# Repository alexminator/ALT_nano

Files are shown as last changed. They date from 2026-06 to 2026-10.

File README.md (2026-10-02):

<h1 align="center">
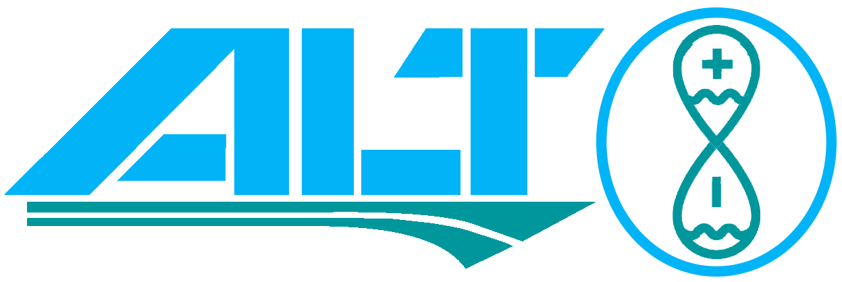
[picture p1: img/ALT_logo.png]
ALT logo
  <br/><strong>Another Level Tank</strong>
  
  <a href="https://github.com/alexminator/ALT_nano/blob/master/README_es.md">
    
  </a>
  <a href="https://github.com/alexminator/ALT_nano/blob/master/README.md">
    
  </a>
</h1>

<h1 align="center">
  


 



  
</h1> 

<h4 align="center">:star: Give me one star — it will motivate me to keep improving it!!</h4>

<!-- TABLE OF CONTENTS -->
<details>
  <summary>Table of contents</summary>
  <ol>
    <li>
      <a href="#about-the-project">About the Project</a>
      <ul>
        <li><a href="#goals-of-this-project-">Goals of this project</a></li>
      </ul>
    </li>
    <li>
      <a href="#getting-started">Getting Started</a>
      <ul>
        <li><a href="#component">Component</a></li>
        <li><a href="#installation">Installation</a></li>
        <li><a href="#diagram">Diagram</a></li>
        <li><a href="#build-and-upload">Build and upload</a></li>
      </ul>
    </li>
    <li><a href="#calibration-and-configuration">Calibration and configuration</a></li>
    <li><a href="#operation">Operation</a></li>
    <li><a href="#troubleshooting">Troubleshooting</a></li>
    <li><a href="#to-do">To do</a></li>
    <li><a href="#collaborator">Collaborator</a></li>
    <li><a href="#license">License</a></li>
    <li><a href="#contact">Contact</a></li>
    <li><a href="#open-source-programs">Open Source Programs</a></li>
    <li><a href="#special-thanks">Special thanks</a></li>
  </ol>
</details>

<!-- ABOUT THE PROJECT -->
## About the Project

ALT_nano is an Arduino-based tank monitor. An ultrasonic sensor measures the distance from the sensor to the water surface, and a 20×4 LCD shows the estimated level and volume. A buzzer signals configurable low- and high-level alarms; the button silences an active alarm or wakes the display backlight. This project is a monitoring aid and is not a certified overflow-protection system.

**You can view the demo [here](https://wokwi.com/projects/356392498196222977).**
> **Warning** :
In Wokwi, press **Start** and click the ultrasonic sensor to change its simulated distance. The firmware currently accepts readings from **20 to 104 cm** (`DEAD_ZONE` and `DIST_TOPE`). At 104 cm the tank is treated as empty; a 20 cm reading maps to 100% on the configured scale. For that reading to represent a physically full tank, the sensor offset above the tank rim (`S`) must also be 20 cm, matching `DEAD_ZONE`. The JSN-SR04T documentation specifies a nominal 25 cm blind zone; for a 25 cm mounting offset, set both `S` and `DEAD_ZONE` to 25 cm after confirming reliable readings with your sensor. The displayed 100% is a software scale, not a guarantee that the tank cannot overflow.

### Goals of this project :

- **_24/7 tank level monitoring_**
- **_Avoid spillage of water due to overflow_**
- **_Prevent the tank from being empty and leaving the house without a water supply_**



---

<!-- GETTING STARTED -->
## Getting Started



```js
         .8.          8 8888         8888888 8888888888
        .888.         8 8888               8 8888
       :88888.        8 8888               8 8888
      . `88888.       8 8888               8 8888
     .8. `88888.      8 8888               8 8888
    .8`8. `88888.     8 8888               8 8888
   .8' `8. `88888.    8 8888               8 8888
  .8'   `8. `88888.   8 8888               8 8888
 .888888888. `88888.  8 8888               8 8888
.8'       `8. `88888. 8 888888888888       8 8888

```
### Component

This project uses an Arduino Nano, a 20×4 parallel LCD, an ultrasonic distance sensor, a buzzer, and a push button. The example hardware uses a waterproof **JSN-SR04T** sensor. If you use another sensor, confirm its voltage, range, timing, and minimum reliable distance before connecting it.

The Arduino(Hardware) components required are:

- **Arduino Nano**
- **LCD screen 20x4**
- **A button**
- **A buzzer**
- **A 10 kΩ resistor** (button pull-up)
- **A 10 kΩ potentiometer** (LCD contrast)
- **A waterproof ultrasonic sensor [JSN-SR04T](https://naylampmechatronics.com/img/cms/Datasheets/JSN-SR04T-2-0.pdf)**



---

### Installation

*Below is the connection diagram and a table with the pins to be connected.*

| ARDUINO PINS | LCD PINS |  
| --- | --- |
|  12-  `D12`  | 15 - `A`  |
|  11-  `D11`  | 4 - `RS`  |
|  10-  `D10`  | 6 - `E` |
|  9-  `D9` | 11 - `D4` |
|  8-  `D8` | 12 - `D5` |
|  7-  `D7` | 13 - `D6` |
|  6-  `D6` | 14 - `D7` |
| GND | 16 - `K`  |
| GND | 1 - `VSS` |
| VCC(5v) | 2 - `VDD` |
| ARDUINO PINS | BUTTON PINS | 
|  3-  `D3` | 1 - 3 | 
| GND | 2 - 4 |  
| ARDUINO PINS | BUZZER PINS |
|  4-  `D4` | + |
| GND | - |
| ARDUINO PINS | JSN-SR04T |
|  2-  `D2` |  `TRIGGER`  |
|  5-  `D5` | `ECHO` |
| VCC(5v) | VCC |
| GND | GND |

**LCD setup:** Connect `R/W` (LCD pin 5) to GND. Connect `V0` (pin 3, contrast) to the wiper of a 10 kΩ potentiometer, with its ends connected to 5 V and GND. Adjust the potentiometer until the characters are visible.

> **Button wiring:** This firmware configures D3 as `INPUT` (not `INPUT_PULLUP`). Wire the button and external 10 kΩ pull-up resistor according to the circuit diagram, and verify that the input reads HIGH when idle and LOW when pressed. Do not connect the LCD backlight pin directly if the module's current exceeds the Arduino pin rating; use an appropriate transistor/driver if needed.

### Diagram

Diagram

> ### :point_right: You can find the diagram [here](https://github.com/alexminator/ALT_nano/blob/master/img/ALT-UNO.fzz). :star:


---

## Build and upload

This is a PlatformIO project for an **Arduino Nano ATmega328P**. Install [VS Code](https://code.visualstudio.com/) and the [PlatformIO IDE extension](https://platformio.org/install/ide?install=vscode), open this repository as a project, and allow PlatformIO to install the dependencies listed in `platformio.ini`. Select the Nano ATmega328P board profile (and the correct bootloader/processor variant if your board requires it).

From the PlatformIO terminal, build and upload with:

```sh
pio run
pio run --target upload
```

Select the correct serial port in PlatformIO if it is not detected automatically. To use the command line, install PlatformIO Core and run the same commands from the project directory.

## Code and debugging

The `Tank` library draws the tank animation; `LiquidCrystal` drives a parallel 20×4 LCD; `NewPing` reads the ultrasonic sensor. The other source files handle alarms, sound, custom LCD characters, and diagnostics. The current firmware uses a **parallel LCD**, not an I2C backpack. Switching to I2C requires changing the library, pin wiring, and initialization.

To enable diagnostic serial output, change the definition near the top of `src/main.cpp`:

```cpp
#define DEBUGLEVEL DEBUGLEVEL_DEBUGGING
// #define DEBUGLEVEL DEBUGLEVEL_NONE
```

The serial monitor is configured for **9600 baud**. Available verbosity levels are defined in `src/debug.h`.

The ultrasonic sensor measures **D**, the distance from its face to the water surface. **H** is the tank's internal height (top rim to bottom), **S** is the vertical sensor offset above the rim, and **C** is the water-column height (bottom to water surface). The general formula is **C = H + S − D**. With an empty tank, the sensor measures to the bottom, so **`DIST_TOPE = D = H + S`**.

The diagram compares four cases:

1. **Empty tank, sensor flush:** `S = 0`, `C = 0`, and `DIST_TOPE = D = H`.
2. **Empty tank, sensor 25 cm above the rim:** `S = 25 cm`, `C = 0`, and `DIST_TOPE = D = H + S`.
3. **Water at an intermediate level, sensor flush:** `S = 0`, so `C = H − D`.
4. **Water at an intermediate level, sensor 25 cm above the rim:** `S = 25 cm`, so `C = H + S − D`. The 25 cm offset is the nominal JSN-SR04T blind-zone clearance; verify the actual minimum for your sensor.

For the nominal 25 cm setup, configure `DEAD_ZONE = 25 cm` and `DIST_TOPE = H + 25 cm`.

<figure>
  Four tank diagrams showing measurements H, S, D, C and the DIST_TOPE formulas
  <figcaption>Sensor-to-water distance and tank geometry used by the level calculation.</figcaption>
</figure>

### What 100% means for a 110 cm tank

With `H = 110 cm` and `DEAD_ZONE = 25 cm`, the software's maximum liquid-column scale is `DIST_TOPE − DEAD_ZONE`:

- **Sensor flush with the rim (`S = 0`):** `DIST_TOPE = 110 cm`; at the displayed 100%, `C = H − D = 110 − 25 = 85 cm`. The water is still 25 cm below the rim because the blind-zone distance is subtracted from the tank height.
- **Sensor 25 cm above the rim (`S = 25 cm`):** `DIST_TOPE = H + S = 135 cm`; at 100%, `C = 135 − 25 = 110 cm`. When full, `D = 25 cm` and `C = H = 110 cm`, so 100% coincides with the tank rim.

These are example settings, not the current firmware values (`DIST_TOPE = 104 cm`, `DEAD_ZONE = 20 cm`). Configure and verify the values for the actual tank and sensor before using either scale.

<figure>
  Comparison of the 100 percent level in a 110 cm tank with a flush sensor and a sensor 25 cm above the rim
  <figcaption>Example of the configured 100% point for two sensor mounting heights.</figcaption>
</figure>

### Calibration and configuration

The main settings are in `src/main.cpp`:

| Setting | Current value | Meaning |
| --- | ---: | --- |
| `DIST_TOPE` | 104 cm | Sensor-to-bottom reading when the tank is empty. With **H** as tank height and **S** as sensor offset above the rim, use `DIST_TOPE = H + S` (or directly measure this distance with the tank empty). |
| `DEAD_ZONE` | 20 cm | Minimum accepted sensor distance and distance mapped to 100% by the current software scale. The JSN-SR04T specifies a nominal 25 cm blind zone; the current 20 cm setting is empirical. To map 100% to water at the rim while retaining 25 cm clearance, configure both `DEAD_ZONE = 25 cm` and `S = 25 cm`, then recalculate `DIST_TOPE = H + S`. For example, if **H = 104 cm**, use `DIST_TOPE = 129 cm`. Verify your particular sensor's reliable minimum. |
| `MAX_DISTANCE` | 200 cm | Maximum distance requested from NewPing; must cover the installed tank while remaining within the sensor's range. |
| `NIVEL_BAJO` / `NIVEL_ALTO` | 20% / 100% | Low- and high-level alarm thresholds. |
| `ancho`, `largo`, `tabiqueA`, `tabiqueL` | cm | Rectangular tank and central-partition dimensions used by the volume formula. |

Measure and verify these values with the actual tank and sensor. The current firmware uses `DIST_TOPE = 104 cm` and `DEAD_ZONE = 20 cm`; `DIST_TOPE` is the sensor-to-bottom reading when empty (**H + S**), not necessarily the tank's height. The accepted distance interval is currently **20–104 cm**. Readings closer than the configured minimum or farther than `DIST_TOPE` are treated as invalid. The level is clamped to 0–100%; with `S = DEAD_ZONE`, 100% corresponds to the water reaching the tank rim. If these values differ, 100% is only the configured software scale and will not coincide with a physically full tank. In either case, **100% does not guarantee overflow is impossible**: set the high alarm below the actual overflow point and leave a safe margin.

The current volume formula assumes a rectangular tank with one rectangular central partition that displaces water. For another shape or partition, adapt `Sensor::get_volume()`; the LCD volume will otherwise be inaccurate. The sensor-to-water geometry also assumes the water surface is a suitable ultrasonic target; avoid obstructions, narrow openings, turbulence, and angled surfaces where possible. Validate the displayed volume against a known water quantity before relying on it.

### Operation

- The LCD shows level (%), sensor distance (cm), estimated volume (L), and a tank-fill graphic.
- A low- or high-level alarm is confirmed after **10 consecutive valid readings** at the threshold. Invalid sensor readings are filtered; after **3 consecutive invalid readings**, the display reports a sensor error.
- Hold the button to silence an active alarm. The alarm can sound again after its condition clears and reoccurs.
- A button press wakes the LCD backlight. The backlight automatically turns off after about **60 seconds**; an active alarm wakes it.

### Troubleshooting

| Symptom | Checks |
| --- | --- |
| `ERROR` on the LCD | Check sensor power, common GND, TRIG on D2, ECHO on D5, sensor aim, and whether the measured gap is within `DEAD_ZONE`–`DIST_TOPE`. |
| Level or volume looks wrong | Re-measure `DIST_TOPE` and tank dimensions; confirm cm units and that the tank shape matches the formula in `get_volume()`. |
| Readings jump near the water | Keep the sensor perpendicular to a calm water surface; verify the minimum reliable distance and increase `DEAD_ZONE` if necessary. |
| Alarm does not match the desired level | Adjust `NIVEL_BAJO` / `NIVEL_ALTO`; remember that the alarm also requires 10 consecutive readings. |
| LCD is blank or unreadable | Check LCD power/contrast, the parallel wiring table, and the backlight circuit; verify the Nano board/port before uploading. |

This project is a monitoring aid, not a certified safety or overflow-prevention device. Use an independent float switch or other fail-safe where overflow could cause damage. The ultrasonic sensor, wiring, and electronics must be installed in a suitably protected environment.



---

## To do

The following items are ideas for future development; they are **not implemented in the current firmware**.

*Make a universal version of the project that includes the following features.*

**_For the software part:_**

+ Include a menu to configure **ALL** possible variables.
  - Tank type. For an accurate calculation of the volume of water.
      * Cylindrical or rectangular.
  - Tank dimensions. The height of the tank can be entered both manually and automatically.
  - Level to activate the alarm for low and high.
  - Choice of the working mode of the device. 
      * Manual the user makes the decisions. 
      * Automatic when reaching the low level of the tank, the level in the cistern will be measured, if it is sufficient, the pump will be activated and the tank will be filled.
  - Choice of alarm tone.
  - Include the incoming water flow to be displayed on the screen.
  - Choice of information to display on the screen.

**_For the hardware part:_**

+ Being able to use different screens. 
     - LCD.
     - OLED
+ Increase the number of buttons to 3, for easy menu navigation.
+ Add relay module to control the tank filling pump.
+ Add a flow sensor to protect the filling pump and account for the amounts of water entering the tank.
+ Add a second ultrasonic sensor to measure the level of the reservoir and that the filling is automatic when the low level is reached.
+ And finally, if time is enough for me, I can make a version with esp32 that includes an embedded website and do all the control from your mobile.



---

## Collaborator

<table style="width:100%">
  <tr>
    <th><b>Alexminator</b></th>
    <th><b>20-EverGreen-2</b></th>
    
  </tr>
  <tr>
    <td align="center"><a href="https://github.com/alexminator">alexminator</a></td>
    <td align="center"><a href="https://github.com/20-EverGreen-2">20-EverGreen-2</a></td>
    
  </tr>
  <tr>
    <td align="center">  </td>
    <td align="center"></td>
    
  </tr>
</table>

## License

*The ALT project is released under the [MIT](LICENSE) license.*

## Contact

> **_Need help?_** 
**_Feel free to contact me 📨 [alexminator99@gmail.com](mailto:alexminator99@gmail.com?Subject=ALT_nano_issues)_**

 

## Open Source Programs
* [VSCODE](https://code.visualstudio.com/) -A source code editor.
* [PlatFormio](https://platformio.org/) - Open programming IDE for C/C++, hardware oriented.

## Special thanks
* _To the Cuban Arduino community._
* _To everyone who gave me his help when I had doubts, especially my son._



---

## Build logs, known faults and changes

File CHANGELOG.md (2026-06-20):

# Changelog - ALT_nano

## [2026-06-20] - Revisión y Corrección de Bugs

### 🐛 Bugs Críticos Corregidos

#### 1. División por cero en `buzz()` (`src/buzzer.h`)
- **Problema:** `buzzer_intro()` llamaba a `buzz(BUZZER_PIN, 0, noteDuration)` para silencios entre notas. Con `frequency=0`, el cálculo `1000000 / frequency / 2` causaba una división por cero, colgando el Arduino.
- **Solución:** Agregado guard `if (frequency <= 0) return;` al inicio de `buzz()`.

#### 2. Índice CGRAM fuera de rango en `createChars()` (`src/font.h`)
- **Problema:** El LCD HD44780 solo tiene 8 slots CGRAM (0-7), pero `createChars()` registraba el carácter `LT` en el slot 8 (inválido). Además `lcd.write(8)` en `printBigCharacters()` no renderizaba un custom character sino un caracter de ROM.
- **Solución:** `LT` movido a slot 0, todos los `lcd.write(8)` → `lcd.write(0)`.

### 🟠 Bugs Graves Corregidos

#### 3. Alarmas bloqueantes (`src/alarms.h`)
- **Problema:** `alarmlow()` y `alarmfull()` usaban bucles `while` que bloqueaban todo el sistema: no se leía el sensor, no se actualizaba la pantalla, y el botón era la única salida. Si el botón fallaba, el sistema quedaba atrapado para siempre.
- **Solución:** Reescritura completa del sistema de alarmas usando `millis()` no bloqueante. El buzzer suena cada 2 segundos en vez de constantemente. El botón se lee en cada ciclo del `loop()` principal. Los contadores se resetean correctamente al descartar la alarma.

#### 4. Doble lectura del sensor por ciclo (`src/main.cpp`)
- **Problema:** `get_dist()` se llamaba dos veces por cada `loop()` — una dentro de `get_level()` y otra directamente. Cada llamada ejecuta `ping_median()` (5 lecturas ultrasónicas), duplicando el tiempo del loop (~300ms total) y el consumo de energía.
- **Solución:** `distance` se cachea dentro de `get_level()` (`distance = currentDistance`) y se eliminó la llamada redundante en `loop()`.

#### 5. Variables zombie `lowlvl`/`lvlfull` (`src/main.cpp`)
- **Problema:** Estas variables globales solo eran usadas por las antiguas funciones de alarma bloqueantes. Quedaron huérfanas tras la refactorización.
- **Solución:** Eliminadas.

#### 6. Contadores de alarma sin reset (`src/alarms.h`)
- **Problema:** `low_read` y `full_read` nunca se reseteaban después de una alarma, causando que siguieran incrementándose sin límite (eventual overflow de `int`). La alarma se re-ejecutaba inútilmente cada ciclo sin sonar.
- **Solución:** Reseteo de contadores al descartar la alarma (líneas 28, 53) y al volver a nivel normal (líneas 61-62).

#### 7. Include guard en `Tank.cpp` (`lib/Tank/Tank.cpp`)
- **Problema:** Todo el archivo de implementación estaba envuelto en `#ifndef Tank_h` / `#define Tank_h` / `#endif`, que es un patrón de headers, no de archivos .cpp. Podía causar problemas de linking en ciertos entornos.
- **Solución:** Eliminado el include guard. El archivo ahora solo contiene los `#include` necesarios y la implementación.

#### 8. Array mal indexado en glyph `BC20` (`lib/Tank/Tank.cpp:160`)
- **Problema:** En el caso `BC20` del switch, la última línea del array escribía en `array[0]` en vez de `array[7]`, sobrescribiendo el primer byte y causando un glitch visual en la representación del 20% del tanque.
- **Solución:** Cambiado `array[0] = 0x00;` → `array[7] = 0x00;`.

#### 9. Backlight sin reset al activarse por alarma (`src/alarms.h`)
- **Problema:** Cuando una alarma encendía el backlight (que estaba dormido), no se reseteaba `startMillis`. En el siguiente ciclo del `loop()`, la comprobación de sleep veía que había pasado más de `sleep_time` desde el último apagado, y volvía a apagar el backlight inmediatamente.
- **Solución:** `startMillis = now` al encender el backlight desde las alarmas.

### 🚀 Mejoras Implementadas

#### 10. Watchdog Timer (`src/main.cpp`, `src/buzzer.h`)
- Agregado `#include <avr/wdt.h>` y `wdt_enable(WDTO_4S)` en `setup()`.
- `wdt_reset()` al inicio de cada `loop()`.
- `wdt_reset()` adicional dentro de los loops de `buzzer_finish()` para prevenir reset durante la reproducción de tonos largos (~360ms).
- **Beneficio:** Si el software se cuelga (bucle infinito, división por cero no atrapada, etc.), el watchdog reinicia el Arduino automáticamente después de 4 segundos.

#### 11. Wake de backlight por botón (`src/main.cpp`)
- Al presionar cualquier botón (press o hold), el backlight se enciende y el timer de sleep se resetea.
- **Beneficio:** El usuario puede "despertar" la pantalla sin esperar a una alarma.

#### 12. Histéresis en detección de fallo del sensor (`src/main.cpp`)
- Variables agregadas: `sensorFailCount`, `SENSOR_FAIL_THRESHOLD = 3`.
- Se requieren 3 lecturas malas consecutivas para declarar `sensorFail = true`.
- Se requieren 3 lecturas buenas consecutivas (decremento por cada una) para limpiar `sensorFail`.
- **Beneficio:** Elimina falsos positivos por lecturas erráticas esporádicas del sensor ultrasónico.

#### 13. Macros de notas musicales sin fugas (`src/buzzer.h`)
- `#define NOTE_C7` etc. movidas fuera de `buzzer_intro()` y convertidas a `static const int`.
- **Beneficio:** Las constantes ya no contaminan el namespace global. Type-safe.

#### 14. Arrays de melodía en flash en vez de stack (`src/buzzer.h`)
- Arrays `melody[]` y `tempo[]` cambiados a `static const`.
- **Beneficio:** Ya no se copian al stack cada vez que se llama a `buzzer_intro()`. Ahorran RAM (~60 bytes) en un microcontrolador con solo 2KB.

#### 15. Dependencia muerta eliminada (`platformio.ini`)
- `bblanchon/ArduinoTrace@^1.2.0` eliminado de `lib_deps` porque nunca se usa en el código.
- **Beneficio:** Libera ~2KB de flash de programa.

#### 16. Link-Time Optimization activado (`platformio.ini`)
- Agregado `build_flags = -flto`.
- **Beneficio:** Reduce el tamaño del binario final eliminando código muerto entre unidades de compilación.

#### 17. Borrado preciso de campos LCD (`src/main.cpp`)
- Los espacios "mágicos" de ancho fijo (8, 10, 16 espacios) se reemplazaron por padding del tamaño exacto del campo (3 chars para nivel/distancia, 7 para volumen).
- `litros` ahora se imprime con 1 decimal (`litros, 1`) para controlar el ancho.
- **Beneficio:** Elimina caracteres fantasma en la LCD al cambiar entre valores de diferente longitud.

#### 18. Ternarias redundantes eliminadas (`src/main.cpp`)
- `isValidReading()` y `isRandomReading()` ya no usan `? true : false` innecesario.
- **Beneficio:** Código más limpio, sin cambio de comportamiento.

#### 19. `buzzer_notify()` refactorizado (`src/buzzer.h`)
- Los números mágicos repetitivos (`56.818125`) se reemplazaron por constantes con nombre.
- El patrón repetido de 5 notas se reemplazó por un array + bucle `for`.
- **Beneficio:** Código mucho más mantenible y legible.

#### 20. Variables muertas eliminadas (`src/main.cpp`)
- `duration` (nunca leída), `char_y` (nunca usada) eliminadas.
- **Beneficio:** menos basura global, ~4 bytes de RAM liberados.

#### 21. `sizeof` idiomático (`src/buzzer.h`)
- `sizeof(melody) / sizeof(int)` → `sizeof(melody) / sizeof(melody[0])`.

#### 22. Conflicto NewPing/Tone por TIMER2 resuelto (`.pio/libdeps/.../NewPing.h`)
- **Problema:** NewPing y la librería `tone()` de Arduino intentan usar TIMER2 simultáneamente, causando `multiple definition of __vector_7` en el linkeo.
- **Solución:** Agregado `__AVR_ATmega328P__` a la lista de microcontroladores que deshabilitan el timer de NewPing. Esto no afecta a `ping_median()` (que usa `delayMicroseconds()`).

#### 23. Boot loop por watchdog en `setup()` (`src/main.cpp`, `src/buzzer.h`)
- **Problema:** `wdt_enable(WDTO_4S)` al inicio de `setup()` iniciaba la cuenta regresiva, pero `setup()` tarda ~5s en total (logo + `buzzer_intro` de ~3s + `delay`s). El watchdog reseteaba el chip antes de alcanzar `loop()`, causando un ciclo infinito de reinicios.
- **Solución:** Agregados `wdt_reset()` estratégicos: antes y después de `buzzer_intro()` en `setup()`, y dentro del bucle de notas de `buzzer_intro()` para que cada nota (~190ms) refresque el watchdog.

### 📊 Resumen de Archivos Modificados

| Archivo | Cambios |
|---|---|
| `src/main.cpp` | WDT, cacheo de sensor, histéresis, wake por botón, limpieza de variables, padding LCD |
| `src/alarms.h` | Reescritura completa no bloqueante, reset de contadores y backlight |
| `src/buzzer.h` | Guard división por cero, const int, arrays static, wdt_reset, refactor notify |
| `src/font.h` | CGRAM slot 0 para LT, write(0) en vez de write(8) |
| `lib/Tank/Tank.cpp` | array[7] corregido, include guard movido a Tank.h |
| `lib/Tank/Tank.h` | Include guard agregado |
| `platformio.ini` | ArduinoTrace eliminado, -flto agregado, monitor_speed |

### 🧹 Limpieza de Conflictos Merge

#### 24. Eliminación de marcadores de conflicto git y código duplicado
- **Problema:** Todos los archivos modificados (`main.cpp`, `buzzer.h`, `alarms.h`, `font.h`) tenían marcadores `<<<<<<<`, `=======`, `>>>>>>>` de un merge conflict mal resuelto. Ambos lados del conflicto se conservaron, resultando en funciones duplicadas, lógica corrupta y código que no compilaba.
- **Solución en `main.cpp`:** Eliminados duplicados de `isValidReading()`, `isRandomReading()`, `get_level()` (lógica de sensor duplicada con ambos lados del merge), `show_info()` (tres campos impresos dos veces), y `loop()` (lectura doble del sensor).
- **Solución en `buzzer.h`:** Reescrito completamente para eliminar versiones duplicadas de `buzzer_intro()`, `buzzer_notify()` y `buzzer_finish()`.
- **Solución en `alarms.h`:** Eliminada versión antigua bloqueante embebida dentro de la nueva función `alarmcheck()`.
- **Solución en `font.h`:** Eliminados `lcd.createChar(8, LT)` duplicado y bloques de renderizado duplicados para caracteres 'O' y 'A'.

## [2026-06-20] - Segunda Revisión: Include Guard, Ghost A, Mejoras

### 🔴 Crítico

#### 25. Include guard en el archivo equivocado (`lib/Tank/Tank.h`, `lib/Tank/Tank.cpp`)
- **Problema:** `Tank.cpp` tenía `#ifndef Tank_h`/`#define Tank_h`/`#endif` envolviendo toda la implementación (válido para headers, no para .cpp). `Tank.h` no tenía include guard — si se incluía dos veces desde distintos módulos, fallaba en compilación.
- **Solución:** Movido el include guard a `Tank.h` (antes de `#include <LiquidCrystal.h>`), eliminado de `Tank.cpp`.

### 🟠 Graves

#### 26. Carácter fantasma "A" al descartar alarma (`src/main.cpp`)
- **Problema:** La alarma imprime `"ALARMA NIVEL BAJO"` empezando en columna 1, fila 0. `show_info()` limpiaba desde columna 2 con 16 espacios, dejando visible la "A" de "ALARMA" en columna 1.
- **Solución:** `lcd.setCursor(2, 0)` → `lcd.setCursor(0, 0)` con 20 espacios para limpiar toda la fila 0.

### 🟡 Medios

#### 27. Asignación redundante en BC20 (`lib/Tank/Tank.cpp`)
- `array[0] = 0x00;` duplicado tras `array[7] = 0x00;` (merge leftover). Eliminado.

#### 28. Variable `char_y` declarada pero nunca usada (`src/main.cpp`)
- Eliminada. Ahorro: 1 byte de RAM.

#### 29. Draw struct con miembro `level` muerto (`src/main.cpp`)
- `levels()` usaba la global `nivel`, ignorando `this->level`. Eliminado el campo y la inicialización.

### 🚀 Mejoras

#### 30. DEBUGLEVEL cambiado a NONE para producción (`src/main.cpp`)
- `DEBUGLEVEL_DEBUGGING` → `DEBUGLEVEL_NONE`. Ahorro: ~3600 bytes de flash (todo el código de Serial.print compilado condicionalmente).

#### 31. `randomReadingsThreshold` hecho `const` (`src/main.cpp`)
- Era `int randomReadingsThreshold = 2;` — ahora `const int`. El compilador puede optimizar mejor.

#### 32. Debounce competitivo eliminado en `get_level()` (`src/main.cpp`)
- Había dos mecanismos de recuperación de `sensorFail` compitiendo: uno gradual (decremento de `sensorFailCount` en cada lectura buena) y uno instantáneo (`sensorFail = false` incondicional). Eliminado el instantáneo; el gradual es más robusto.

#### 33. `ledbacklight` sincronizado en alarmas (`src/alarms.h`)
- Cuando una alarma encendía el backlight físico (`digitalWrite(LEDBACK, HIGH)`), la variable `ledbacklight` quedaba en `false`. Agregado `ledbacklight = true` en ambos bloques de alarma (baja y alta).

### 🐛 Corrección de Regresión en Alarma

#### 34. Texto de alarma parpadeante (`src/main.cpp`)
- **Problema:** `show_info()` borraba la línea 0 completa en cada ciclo del `loop()`, y `alarmcheck()` escribía el texto de alarma justo antes. El resultado era que el texto se borraba y reescribía cada ~200ms, causando un parpadeo visible.
- **Solución:** El borrado de la línea 0 ahora es condicional: solo se limpia cuando NO hay alarma activa (`low_read < sameReadings && full_read < sameReadings`).

#### 35. Alarma con sonido continuo no bloqueante (`src/buzzer.h`, `src/alarms.h`)
- **Problema:** `buzzer_finish()` usaba `delay(3.6ms)` dentro de un bucle, bloqueando el sistema ~360ms. Se llamaba cada 2 segundos (intervalo fijo), por lo que la sirena sonaba a saltos en vez de continua.
- **Solución:** Reemplazado por `buzzer_sweep_update()`, una máquina de estados no bloqueante que avanza un paso del barrido de frecuencia (1000→2600Hz→1000Hz) en cada llamada. Se invoca desde `loop()` sin ningún `delay()`. El sonido ahora es continuo y el sistema nunca se bloquea.
  - `buzzer_sweep_start()` — inicia el barrido
  - `buzzer_sweep_update()` — avanza un paso (se llama desde loop())
  - `buzzer_sweep_stop()` — detiene el barrido (al descartar alarma o al volver a nivel normal)

### 📊 Resumen de Memoria

| Versión | Flash | RAM |
|---|---|-----|
| Antes de esta revisión | 65.1% (20002B) | 37.1% (759B) |
| Después | **53.2% (16356B)** | **29.1% (595B)** |
| **Ahorro** | **11.9% (3646B)** | **8.0% (164B)** |

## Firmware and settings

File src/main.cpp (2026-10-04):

#include <Arduino.h>
#include <avr/wdt.h>
#include "sensor_math.h"

// Declare the debugging level then include the header file.
// Choose DEBUGLEVEL_NONE if you don't want to show anything in console
//#define DEBUGLEVEL DEBUGLEVEL_DEBUGGING
#define DEBUGLEVEL DEBUGLEVEL_NONE
#include "debug.h"
// Declare what message you want to display on the console.
// User picks console message from this list
// This selection will not be effective if DEBUGLEVEL is DEBUGLEVEL_NONE
#define DISTANCE
#define LEVEL
#define VOLUMEN

// Librerias Globales
#include <NewPing.h>
#include <LiquidCrystal.h>
// LCD module connections (RS, E, D4, D5, D6, D7)
LiquidCrystal lcd(11, 10, 9, 8, 7, 6);

//-------------lcd---------
char data1[] = "ALT";
char data2[] = "ERROR";
byte char_x = 0;
#define LEDBACK 12 // To control the LCD backlight

//---------Variables del tanque---------
#define DIST_TOPE 104        // maximum level, measured with the tank empty in cm
const int NIVEL_BAJO = 20;   // low level percentage from which I give a low level alarm
const int NIVEL_ALTO = 100;  // high percentage level from which I give a full tank alarm
const float ancho = 195.5;   // cm
const float largo = 200.0;   // cm
const float tabiqueA = 14.5; // partition width cm
const float tabiqueL = 200;  // septum length cm
float columnaLiquida;
float VolumenDinamicoTabique;
float litros;
const int sameReadings = 10;     // number of consecutive readings to consider it valid. Avoid sounding alarm with bad readings
int low_read = 0;                // counter reading of low level
int full_read = 0;               // counter reading of full level
// const int randomReadingsThreshold = 2;  // No longer needed - all invalid readings are sensor errors

//JSN-SR04 sensor. Detection range: 20cm -450cm
#define DEAD_ZONE 20  // Dead zone in cm; confirm the exact minimum distance for your sensor model
#define MAX_DISTANCE 200 // Maximum distance we want to ping for (in centimeters). Maximum sensor distance is rated at 400-500cm.
#define TRIGGER_PIN 2
#define ECHO_PIN 5
NewPing sonar(TRIGGER_PIN, ECHO_PIN, MAX_DISTANCE); // NewPing setup of pins and maximum distance.


//------------- Button---------
#define KEYPIN 3 // button is connected to pin 3(INT 1)

// Button debouncing
const uint8_t DEBOUNCE_DELAY = 10; // in milliseconds
struct Button
{
  // state variables
  uint8_t pin;
  bool lastReading;
  uint32_t lastDebounceTime;
  uint16_t state;

  // methods determining the logical state of the button
  bool pressed() { return state == 1; }
  bool released() { return state == 0xffff; }
  bool held(uint16_t count = 0) { return state > 1 + count && state < 0xffff; }

  // method for reading the physical state of the button
  void read()
  {
    // reads the voltage on the pin connected to the button
    bool reading = digitalRead(pin);

    // if the logic level has changed since the last reading,
    // we reset the timer which counts down the necessary time
    // beyond which we can consider that the bouncing effect
    // has passed.
    if (reading != lastReading)
    {
      lastDebounceTime = millis();
    }

    // from the moment we're out of the bouncing phase
    // the actual status of the button can be determined
    if (millis() - lastDebounceTime > DEBOUNCE_DELAY)
    {
      // don't forget that the read pin is pulled-up
      bool pressed = reading == LOW;
      if (pressed)
      {
        if (state < 0xfffe)
          state++;
        else if (state == 0xfffe)
          state = 2;
      }
      else if (state)
      {
        state = state == 0xffff ? 0 : 0xffff;
      }
    }

    // finally, each new reading is saved
    lastReading = reading;
  }
};
// Creating the button object with {pin, lastReading, lastDebounceTime, state}
Button button = {KEYPIN, HIGH, 0, 0};

// Ultrasonic data
bool sensorFail = false;
int sensorFailCount = 0;               // Consecutive bad reading counter
const int SENSOR_FAIL_THRESHOLD = 3;   // Bad readings before declaring sensor error
int nivel = 0;                         // level in %
int distance;
int currentDistance; 
int lastDistance;        // Variable to store the last valid sensor reading

//-------------screen time--------
unsigned long startMillis;
unsigned long currentMillis;
const unsigned long sleep_time = 60000; // Time in sec to turn off the backlight 1mint
bool ledbacklight = false;

//-------------Buzzer---------
#define BUZZER_PIN 4 // Buzzer BUZZER_PIN

// Draw library
#include "Tank.h"
Tank *draw = new Tank(&lcd); // Creating the draw object with {lcd}
#include "draw.h"
//------------Other libraries-----------
#include "font.h"
#include "buzzer.h"

int countDigit(int num) {
  // If the number is 0, it has 1 digit
  if (num == 0) {
    return 1;
  }

  // If the number is negative, we make it positive
  if (num < 0) {
    num = -num;
  }

  int counter = 0;
  
  while (num > 0) {
    num /= 10; // Divide the number by 10
    counter++; // Increase the counter
  }
  
  return counter; // Returns the number of figures
}
struct Draw
{
  // methods for draw a tank
  void levels() {
  switch (nivel) { 
    case 0 ... 5: 
      empty(); 
      break; 
    case 6 ... 10: 
      ten(); 
      break; 
    case 11 ... 20: 
      twenty(); 
      break; 
    case 21 ... 30: 
      thirty(); 
      break; 
    case 31 ... 40: 
      forty(); 
      break; 
    case 41 ... 50: 
      fifty(); 
      break; 
    case 51 ... 60: 
      sixty(); 
      break; 
    case 61 ... 70: 
      seventy(); 
      break; 
    case 71 ... 80: 
      eighty(); 
      break; 
    case 81 ... 90: 
      ninety(); 
      break; 
    default: 
      full(); 
      break; 
  } 
} 
};

Draw tank; // Creating the object draw tank
struct Sensor
{
  // state variables
  uint8_t trigger;
  uint8_t echo;

  // methods for sensor isValidReading, get_dist, get_level, get_volume and show_info
  bool isValidReading(float currentdistance)
  {
    return SensorMath::isValidReading(currentdistance, DEAD_ZONE, DIST_TOPE); // Rules out sensor errors, discards bad readings.
  }

  float get_dist()
  {
    int measuredDistance = sonar.ping_median() / US_ROUNDTRIP_CM; // Average of 5 readings and converts it to cms.

    #ifdef DISTANCE
    debuglnD("Distancia en tiempo real: " + String(measuredDistance));
    #endif

    return measuredDistance;
  }

  int get_level()
  {
    currentDistance = get_dist();
    distance = currentDistance; // Cache for use in loop() without re-reading sensor

    if (isValidReading(currentDistance)) // Rules out sensor errors, discards bad readings.
    {
      columnaLiquida = SensorMath::liquidColumnCm(DIST_TOPE, currentDistance);
      nivel = SensorMath::levelPercent(columnaLiquida, DIST_TOPE - DEAD_ZONE); // 84 cm maximum liquid column above the 20 cm dead zone

      // Require consecutive good readings to clear an active sensor error.
      if (sensorFail) {
        if (sensorFailCount > 0) sensorFailCount--;
        if (sensorFailCount == 0) sensorFail = false;
      } else {
        sensorFailCount = 0;
      }

      lastDistance = currentDistance;
      distance = lastDistance;

    #ifdef LEVEL
      debuglnD("Nivel en porciento: " + String(nivel));
    #endif
    }
    else
    {
      // Keep displaying the last valid measurement while filtering bad readings.
      distance = lastDistance;
      // Reading outside [DEAD_ZONE, DIST_TOPE] is a sensor error
      // (covers disconnected sensor → 0, sensor too close, out of range, etc.)
      if (sensorFailCount < SENSOR_FAIL_THRESHOLD) {
        sensorFailCount++;
      }
      if (sensorFailCount >= SENSOR_FAIL_THRESHOLD) {
        sensorFail = true; // Trigger only after threshold of consecutive bad readings
      }
    }

    nivel = (nivel < 0) ? 0 : (nivel > 100) ? 100 : nivel;
    return nivel;
  }

  float get_volume()
  {
    VolumenDinamicoTabique = SensorMath::partitionVolumeCm3(tabiqueA, tabiqueL, columnaLiquida); // calculation of the volume of the partition up to the height of the water

  #ifdef VOLUMEN
    debuglnD("Volumen del tabique a una altura de " + String(columnaLiquida) + " cm es de " + String(VolumenDinamicoTabique) + " cm^3.");
  #endif

    float volumenBrutoTanque = SensorMath::grossTankVolumeCm3(ancho, largo, columnaLiquida);

  #ifdef VOLUMEN
    debuglnD("Volumen de agua: " + String(volumenBrutoTanque - VolumenDinamicoTabique) + " cm^3.");
  #endif

    litros = SensorMath::waterVolumeLiters(volumenBrutoTanque, VolumenDinamicoTabique);

    return litros;
  }

  void show_info() {
    static bool lastSensorFail = false; // Track transition for display clearing
    int LvlDigit = countDigit(nivel);
    int LitrosDigit = countDigit(litros);
    int DistanceDigit = countDigit(distance);

    // Draw the tank and info display
  if (!sensorFail)
  {
    // Transition from ERROR to normal: clear stale big-font char codes from DDRAM
    if (lastSensorFail) {
      lcd.clear();
      lastSensorFail = false;
    }
    tank.levels();
    // Volume (max ~7 chars e.g. "3040.8")
    lcd.setCursor(7, 3);
    lcd.print("       ");
    // Keep the decimal value right-aligned in columns 7-13 (digits + ".d").
    lcd.setCursor(12 - LitrosDigit, 3);
    lcd.print(columnaLiquida <= 0 ? 0 : litros, 1);
    // Level % (max 3 chars)
    lcd.setCursor(7, 1);
    lcd.print("   ");
    lcd.setCursor(10 - LvlDigit, 1);
    lcd.print(nivel);
    // Distance (max 3 chars)
    lcd.setCursor(7, 2);
    lcd.print("   "); // Clear
    lcd.setCursor(10 - DistanceDigit, 2);
    lcd.print(distance);
    // Fixed Text
    lcd.setCursor(0, 1);
    lcd.print("Nivel:");
    lcd.setCursor(10, 1);
    lcd.print("%");
    lcd.setCursor(0, 2);
    lcd.print("Dist.:");
    lcd.setCursor(10, 2);
    lcd.print("cm");
    lcd.setCursor(0, 3);
    lcd.print("Vol. :");
    lcd.setCursor(14, 3);
    lcd.print("L");
    // Clear top row only when no alarm is active (avoid flashing alarm text)
    if (low_read < sameReadings && full_read < sameReadings) {
      lcd.setCursor(0, 0);
      lcd.print("                    ");
    }
  }
  else
  {
    if (!lastSensorFail) {
      lastSensorFail = true;
      createChars();
      lcd.clear();
      printBigCharacters(data2, 2, 1); // Print ERROR sensor readings
    }
    // Sound and silence handled by alarm_handler() - not here
  }
  }
};

Sensor ultraSonic = {TRIGGER_PIN, ECHO_PIN}; // Creating the ultraSonic object with {trigPin, echoPin}

// Alarm
#include "alarms.h"

void setup()
{
  // Enable watchdog timer (4 second timeout) for automatic reset on hang
  wdt_enable(WDTO_4S);

  Serial.begin(9600);
  startMillis = millis(); // initial start time

  // Activate the LCD
  lcd.begin(20, 4);
  lcd.clear();

  // Initialize the pins 
  pinMode(BUZZER_PIN, OUTPUT); // buzzer output
  pinMode(KEYPIN, INPUT);      // boton
  pinMode(LEDBACK, OUTPUT);    // backlight
  pinMode(TRIGGER_PIN, OUTPUT);    // Sets the trigPin as an Output
  pinMode(ECHO_PIN, INPUT);     // Sets the echoPin as an Input

  // Turn on Backlight
  digitalWrite(LEDBACK, HIGH);

  // Print the LOGO
  createChars();
  printBigCharacters(data1, 5, 0);
  lcd.setCursor(1, 2);
  lcd.print("Another Level Tank");
  lcd.setCursor(4, 3);
  lcd.print("..Loading..");
  lcd.display();
  wdt_reset(); // Reset watchdog before long operations (~5s total in setup)
  delay(1000);
  buzzer_intro();
  delay(1000);
  lcd.clear();
}

void loop()
{
  // Reset watchdog timer to prevent system reset during normal operation
  wdt_reset();
  button.read();
  buzzer_notify_update(); // Advance alarm arpeggio (non-blocking)

  // Wake backlight on any button press and reset sleep timer
  if (button.pressed() || button.held()) {
    digitalWrite(LEDBACK, HIGH);
    ledbacklight = true;
    startMillis = millis();
  }

  // Get the level and volume (distance is cached inside get_level)
  nivel = ultraSonic.get_level();
  litros = ultraSonic.get_volume();
  alarm_handler();
  ultraSonic.show_info(); // Show the information

  // Sleep LCD. Control backlight lcd
  currentMillis = millis();
  if (currentMillis - startMillis >= sleep_time) // Check the period has elapsed
  {
    digitalWrite(LEDBACK, LOW); // turn off backlight
    ledbacklight = false;
    startMillis = currentMillis;
  }
}

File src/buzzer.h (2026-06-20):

//#########################BUZZER CONTROL#############################################################

// Mario intro melody note frequencies
static const int NOTE_C7 = 2093;
static const int NOTE_E7 = 2637;
static const int NOTE_G7 = 3136;
static const int NOTE_G6 = 1568;

void buzzer_intro() {  // Tone for intro (Mario melody, blocking but only at startup)
  static const int melody[] = {
    NOTE_E7, NOTE_E7, 0, NOTE_E7,
    0, NOTE_C7, NOTE_E7, 0,
    NOTE_G7, 0, 0,  0,
    NOTE_G6, 0, 0, 0,
  };

  static const int tempo[] = {
    12, 12, 12, 12,
    12, 12, 12, 12,
    12, 12, 12, 12,
    12, 12, 12, 12,
  };

  const int size = sizeof(melody) / sizeof(melody[0]);
  for (int thisNote = 0; thisNote < size; thisNote++) {
    wdt_reset(); // Keep watchdog happy during long melody (~3s total)
    int noteDuration = 1000 / tempo[thisNote];
    if (melody[thisNote] > 0) {
      tone(BUZZER_PIN, melody[thisNote], noteDuration);
      delay(noteDuration);
    }
    int pauseBetweenNotes = noteDuration * 1.30;
    delay(pauseBetweenNotes);
  }
}

// Non-blocking ascending arpeggio for all alarms
// Loops continuously while active: 6 notes in ascending pattern
// Uses a state machine that advances one step per call
struct BuzzerNotify {
    bool active;
    uint8_t currentNote;
    unsigned long lastNoteTime;
};

BuzzerNotify buzzerNotify = {false, 0, 0};

// The ascending arpeggio notes (same as buzzer_notify())
static const int NOTIFY_NOTES[] = { 1318, 1567, 2637, 2093, 2349, 3135 };
static const unsigned long NOTIFY_CYCLE_MS[] = { 114, 114, 114, 114, 114, 450 }; // ms between note starts (last has pause before repeat)
static const unsigned long NOTIFY_TONE_MS[] = { 57, 57, 57, 57, 57, 275 }; // tone duration
static const uint8_t NOTIFY_NOTE_COUNT = 6;

void buzzer_notify_start() {
    buzzerNotify.active = true;
    buzzerNotify.currentNote = 0;
    buzzerNotify.lastNoteTime = 0; // Force immediate first note on next update
}

void buzzer_notify_stop() {
    buzzerNotify.active = false;
    noTone(BUZZER_PIN);
}

void buzzer_notify_update() {
    if (!buzzerNotify.active) return;

    unsigned long now = millis();
    if (now - buzzerNotify.lastNoteTime >= NOTIFY_CYCLE_MS[buzzerNotify.currentNote]) {
        buzzerNotify.lastNoteTime = now;
        tone(BUZZER_PIN, NOTIFY_NOTES[buzzerNotify.currentNote], NOTIFY_TONE_MS[buzzerNotify.currentNote]);

        buzzerNotify.currentNote++;
        if (buzzerNotify.currentNote >= NOTIFY_NOTE_COUNT) {
            buzzerNotify.currentNote = 0; // Loop continuously
        }
    }
}

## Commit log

2022-12-26 nrw branch lcd no i2c
2023-02-10 objeto sensor
2023-02-10 funcional con obejtos sensor y boton
2023-02-11 funcional con objetos sensor y boton
2023-02-11 fix button for alarm
    [main.cpp]
2023-02-11 fix button routine
2023-02-14 NewTankIcon_and_MinorChanges New Tank Icon. (Tank.cpp, draw.h) Tank now correctly draw. (Tank.h, Tank.cpp, draw.h)
    Reduced/optimized code (main.cpp)
    [main.cpp]
2023-02-16 move img
    [ALT-UNO.fzz]
2023-02-22 alarm every 20 fail readings
    [main.cpp]
2023-10-01 fix alarm trigger for bad readings
    [main.cpp]
2023-10-01 fix logical error sensor
    [main.cpp]
2026-06-20 fix bugs
    [ALT-UNO.fzz]
2026-10-02 Fix display units and document calibrated tank setup.
    🤖 Generated with Codebuff
    [main.cpp]
2026-10-02 Clarify ultrasonic sensor geometry in both READMEs
2026-10-02 Replace outdated tank figures with bilingual measurement and 100% examples
    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
2026-10-02 cambio de imagenes
2026-10-04 Separate sensor calculations for host-side testing
    Extract sensor math into reusable functions and add native tests so the calculation behavior can be checked before flashing the Nano.
    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
